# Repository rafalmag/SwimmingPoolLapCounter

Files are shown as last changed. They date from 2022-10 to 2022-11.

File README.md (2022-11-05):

# Swimming Pool Lap Counter

Swimming pool lap counter is a device for swimmers, so when practicing swimming in the pool they can easily count how many laps did they swim. 

The design requirements and solutions:
- battery powered  (powered by single cell 18650 powerbank)
- waterproof (fits into watertight food box)
- easy to trigger count increments (by capacitive touch sensing)
- lap count displayed and visible in bright sunlight (eInk display)
- lap increment trigger acknowledged (by buzzer and led)
- ability to reset counter without opening the box
- configuration should not interfere with main use case (lap count) and should not be triggered by mistake.

## Prototype

The ground wire should be grounded.
The blue wire should be connected to aluminum foil to sense touches.

## User interface

After starting the device the lap count resets to 0.
The capacitive sensor if "pressed" (senses touch) for a short time increments the lap count, emits sound and lights LED.
If "pressed" for a long time (>3 sec) it resets the counter.

Configuration options:
- beeper volume - by potentiometer (1k Ohm)
- LED brightness - by potentiometer (1k Ohm)
- touch sensing sensitivity threshold - by potentiometer (10k Ohm)
- (fixed) touch sensing resistor (20M Ohm) ~~- by potentiometer / dip switch~~ (idea abandoned - in practice dip switch and pot caused too much noise)
- increment counter by 2 mode - dip switch (by default increment by 1)
- 5s minimum lap increment interval - dip switch (by default - about 500ms)

## Hardware:
- Arduino Nano

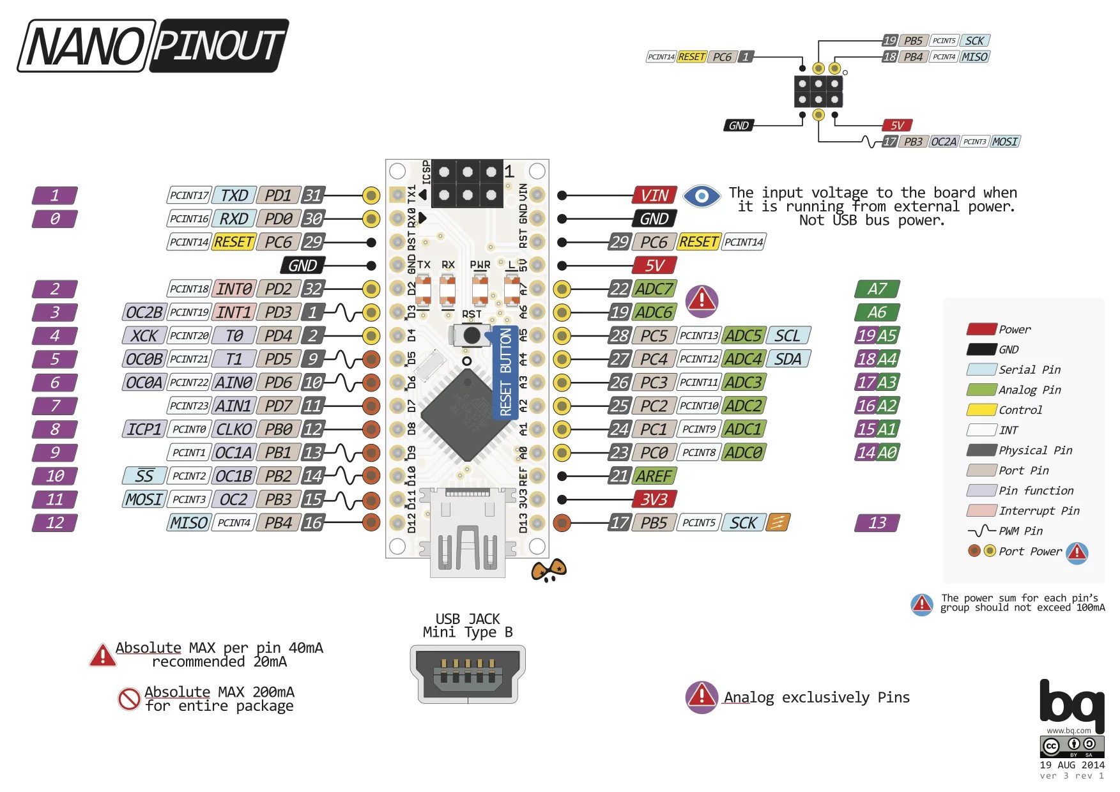
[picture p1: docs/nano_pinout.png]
nano pinout


- e-ink MH-ET LIVE - see https://github.com/MHEtLive/MH-ET-LIVE-E-Papers 
(my only works in 5V mode)

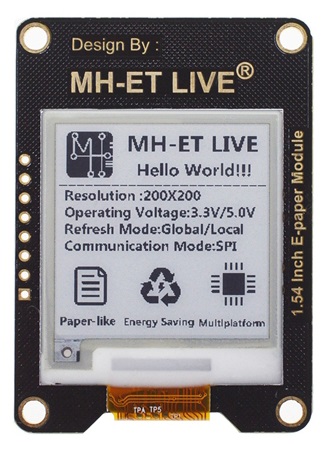
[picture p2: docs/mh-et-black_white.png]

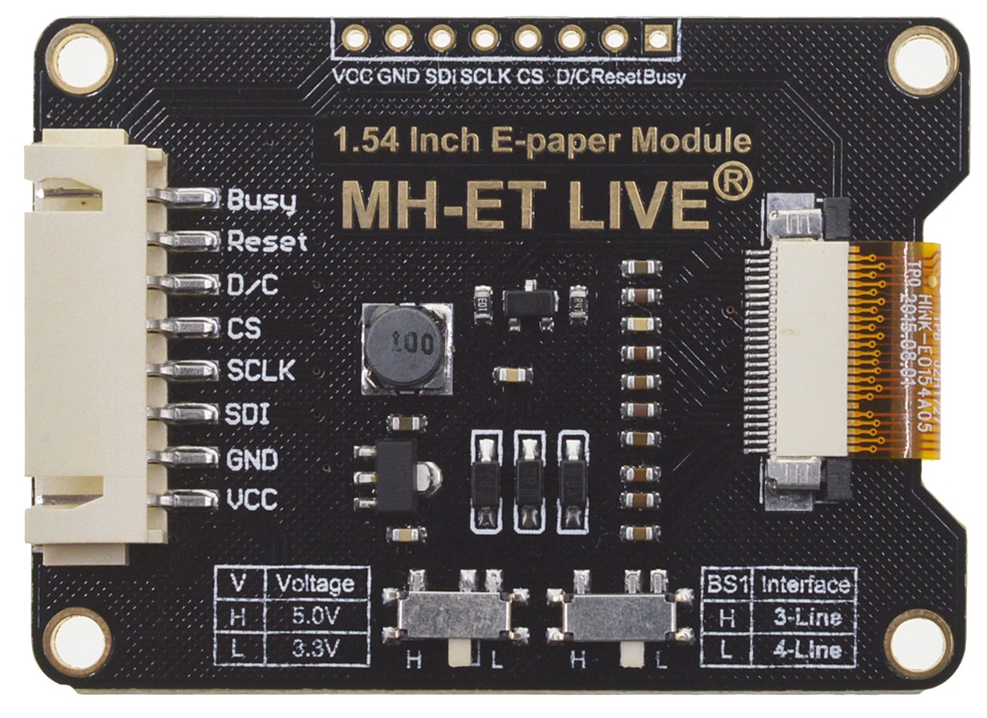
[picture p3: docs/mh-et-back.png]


- active buzzer (5V VCC (2mA when it beeps), GND)
 Consider: on/off toggle (hardware switch and maybe 1k-2kOhm variable resistor for VCC to adjust buzzer volume)
 IO pin connected via D4 .

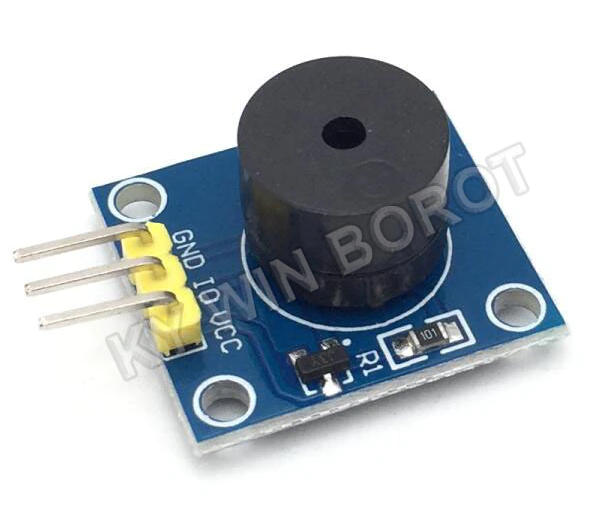
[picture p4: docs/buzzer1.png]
buzzer top

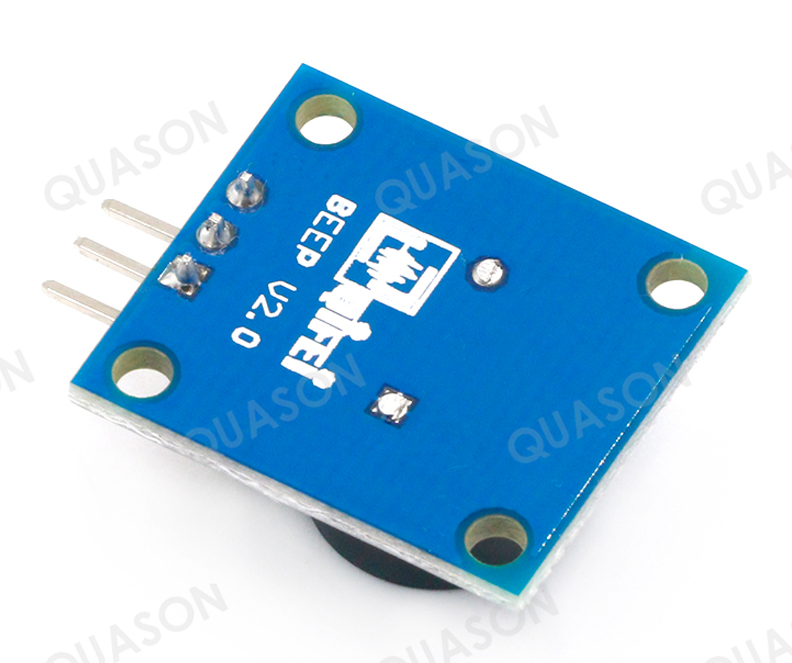
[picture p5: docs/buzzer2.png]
buzzer bottom


 - red 5mm led (2.2V, 10mA) (nano can output 40mA per IO pin, so it would be ok), connected via 330 Ohm resistor to D5

 - small powerbank (with 18650 battery, USB charging input and output - to power the nano and PCB)

## Wiring:

| e-ink / paper | Nano board |
|---|---|
| VCC | 5V |
| GND | GND |
| SDI (DIN) | D11(MOSI)  |
| CLK | D13(SCK) |
| CS | D10 |
| DC | D9 |
| RESET | D8 |
| BUSY | D7 |

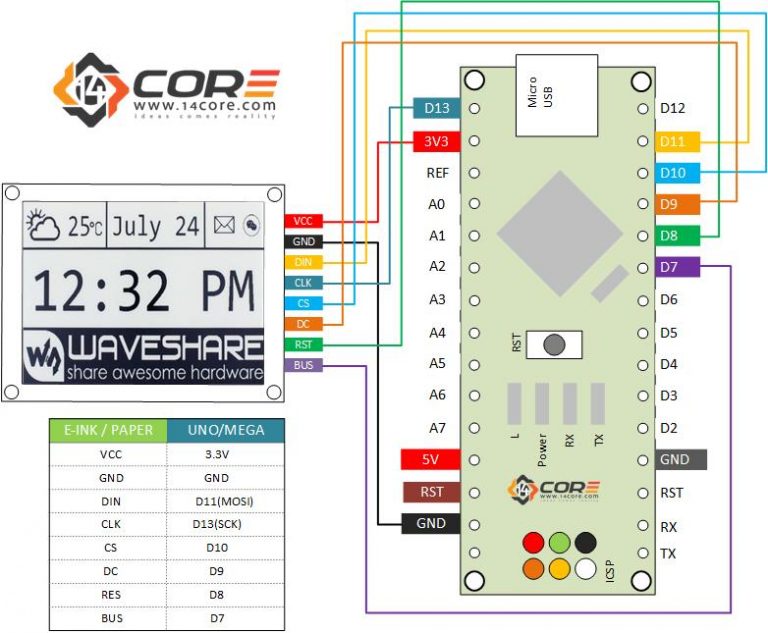
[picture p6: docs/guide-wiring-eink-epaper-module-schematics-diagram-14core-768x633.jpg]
wiring


## Schematic

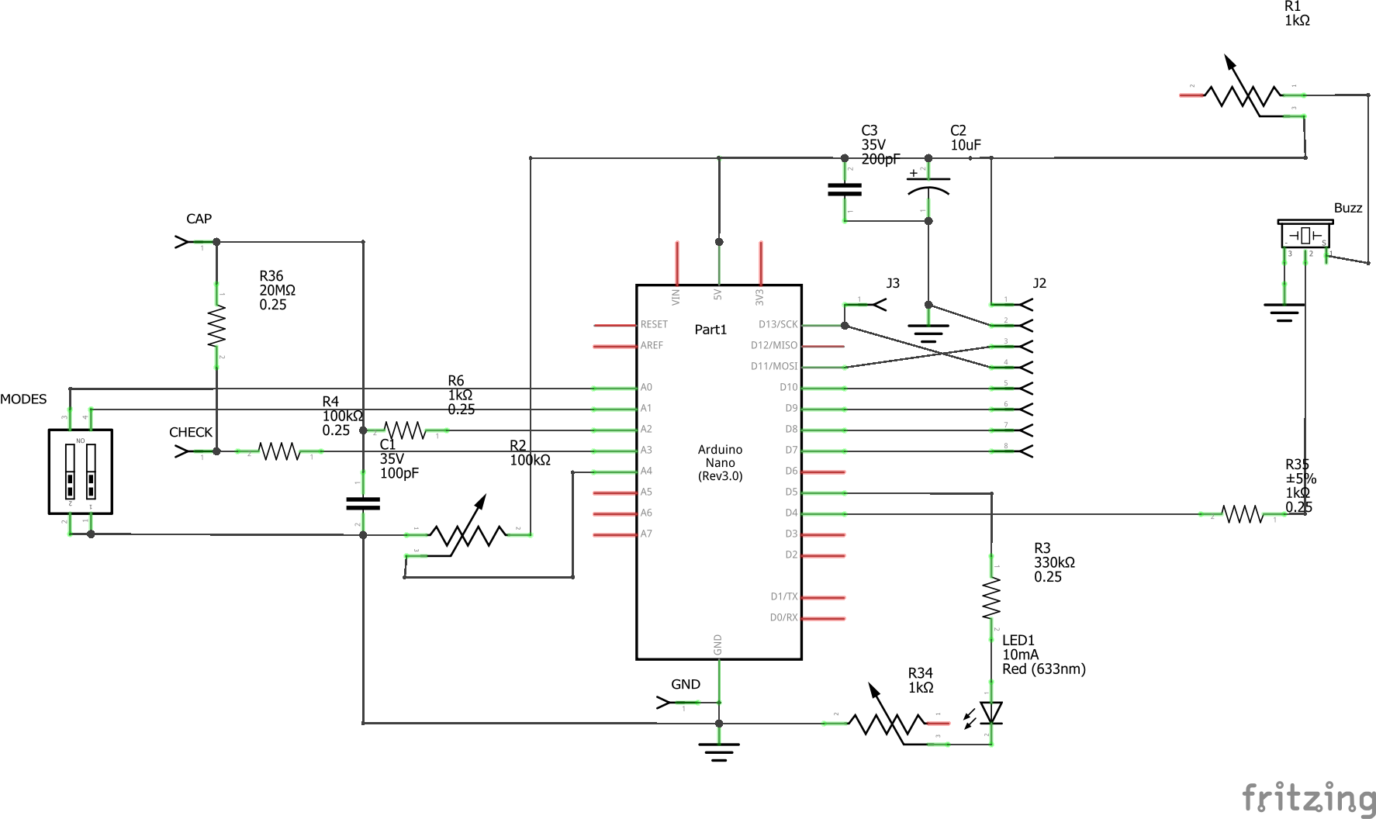
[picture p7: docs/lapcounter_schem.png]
schematic


## PCB design

PCB is based on prototype board 70 x 50mm with THT components soldered on top and SMD on bottom. 
The SMD resistor can be replaced with THT one in vertical mode.

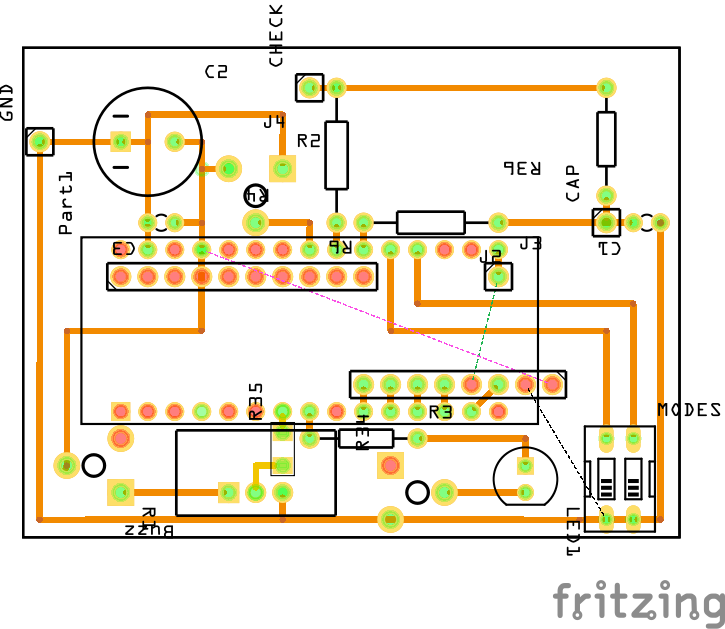
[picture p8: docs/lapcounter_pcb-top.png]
pcb


## Knows issues:
- the EPD library updates the screen in blocks that are multiplications of 8 pixels, but the RRE fonts lib is using blocks of different sizes. This causes minor glitches in the rendered fonts. Because of that issue I did not even tried to use antialiased fonts, but thanks to eInk high resolution the numbers are still readable

## TO DO ideas:
- deep sleep mode (think about user interface for waking up, putting to sleep)
- low battery warning (?)

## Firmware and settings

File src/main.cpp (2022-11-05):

#include <SPI.h>
#include <EPD1in54.h>
#include <EPDPaint.h>

#include "RREFont.h"
#include "rre_term_10x16.h"

#include <CapacitiveSensor.h>
#include <Button.h>
#include <ButtonEventCallback.h>
#include <CapacitiveButton.h>
#include "AnalogPin.h"

RREFont font;

#define COLORED 0
#define UNCOLORED 1

/**
 * Due to RAM not enough in Arduino UNO, a frame buffer is not allowed.
 * In this case, a smaller image buffer is allocated and you have to
 * update a partial display several times.
 * 1 byte = 8 pixels, therefore you have to set 8*N pixels at a time.
 */
unsigned char image[1024];
EPDPaint paint(image, 0, 0); // width should be the multiple of 8
EPD1in54 epd;                // default reset: 8, dc: 9, cs: 10, busy: 7

// D4 and D5
#define BUZZER_PIN PIN4
#define LED_PIN PIN5

#define THRESHOLD_PIN A4
AnalogPin thresholdPin(THRESHOLD_PIN);

#define TWO_LAP_MODE_PIN A0
#define MINIMUM_LAP_INCREMENT_INTERVAL_MODE_PIN A1

CapacitiveButton capacitiveButton = CapacitiveButton(A2, A3);

// screen size
#define SCR_WD 200
#define SCR_HT 200

int lapCount = 0;
#define MINIMUM_LAP_INCREMENT_INTERVAL_MS 5000L
unsigned long lastLapIncrement = millis() - MINIMUM_LAP_INCREMENT_INTERVAL_MS;
boolean canIncrement = false;

void customRect(int x, int y, int w, int h, int c)
{
  int extra_x = x % 8;
  int new_x = x - extra_x;

  paint.setWidth(w + extra_x);
  paint.setHeight(h);

  paint.clear(UNCOLORED);

  paint.drawFilledRectangle(0, 0, w - 1 + extra_x, h - 1, c);
  epd.setFrameMemory(paint.getImage(), new_x, y, paint.getWidth(), paint.getHeight());
  return;
}

void rmInit()
{
  // init-RM

  /**
   *  there are 2 memory areas embedded in the e-paper display
   *  and once the display is refreshed, the memory area will be auto-toggled,
   *  i.e. the next action of SetFrameMemory will set the other memory area
   *  therefore you have to clear the frame memory twice.
   */
  epd.clearFrameMemory(0xFF); // bit set = white, bit reset = black
  epd.displayFrame();
  epd.clearFrameMemory(0xFF); // bit set = white, bit reset = black
  epd.displayFrame();

  paint.setRotate(ROTATE_0);
  paint.setWidth(200);
  paint.setHeight(24);

  /* For simplicity, the arguments are explicit numerical coordinates */
  paint.clear(COLORED);
  paint.drawStringAt(30, 4, "SwimmingPoolLapCounter", &Font16, UNCOLORED);
  epd.setFrameMemory(paint.getImage(), 0, 10, paint.getWidth(), paint.getHeight());

  paint.clear(UNCOLORED);
  paint.drawStringAt(30, 4, "by Rafal Magda", &Font16, COLORED);
  epd.setFrameMemory(paint.getImage(), 0, 30, paint.getWidth(), paint.getHeight());

  epd.displayFrame();
  delay(2000);

  // init-RM end

  /**
   *  there are 2 memory areas embedded in the e-paper display
   *  and once the display is refreshed, the memory area will be auto-toggled,
   *  i.e. the next action of SetFrameMemory will set the other memory area
   *  therefore you have to clear the frame memory twice.
   */
  epd.clearFrameMemory(0xFF); // bit set = white, bit reset = black
  epd.displayFrame();
  epd.clearFrameMemory(0xFF); // bit set = white, bit reset = black
  epd.displayFrame();

  font.setScale(4);
  font.setSpacing(4);
  font.printStr(ALIGN_CENTER, 10, "1234");
  epd.displayFrame();
  font.printStr(ALIGN_CENTER, 50, "5678");
  epd.displayFrame();
}

void incrementLapCount()
{
  if (digitalRead(TWO_LAP_MODE_PIN) == LOW)
  {
    lapCount += 2;
  }
  else
  {
    lapCount++;
  }
  lastLapIncrement = millis();
}

// Use this function to configure the internal CapSense object to suit you. See the documentation at: http://playground.arduino.cc/Main/CapacitiveSensor
// This function can be left out if the defaults are acceptable - just don't call configureButton
void configureCapacitiveButton(CapacitiveSensor &capSense)
{
  // Set the capacitive sensor to timeout after 300ms
  capSense.set_CS_Timeout_Millis(300);
  // Set the capacitive sensor to auto-calibrate every 6secs
  capSense.set_CS_AutocaL_Millis(6000);
}
void dispNumber(int number);

// btn is a reference to the button that fired the event. That means you can use the same event handler for many buttons
void onButtonPressed(Button &btn)
{
  if (lastLapIncrement + MINIMUM_LAP_INCREMENT_INTERVAL_MS < millis() || digitalRead(MINIMUM_LAP_INCREMENT_INTERVAL_MODE_PIN) == HIGH)
  {
    digitalWrite(LED_PIN, HIGH);    // LED on
    digitalWrite(BUZZER_PIN, HIGH); // buzzer on
    canIncrement = true;
  }
}

void onReleaseCallbackFunction(Button &btn, uint_least16_t duration)
{
  if (canIncrement || digitalRead(MINIMUM_LAP_INCREMENT_INTERVAL_MODE_PIN) == HIGH)
  {
    incrementLapCount();
    Serial.print("button pressed ");
    Serial.println(lapCount);
    digitalWrite(BUZZER_PIN, LOW); // buzzer off
    dispNumber(lapCount);
    digitalWrite(LED_PIN, LOW); // LED off
    canIncrement = false;
    delay(250);
  }
  else
  {
    Serial.print("button pressed within MINIMUM_LAP_INCREMENT_INTERVAL_MS, lap count = ");
    Serial.println(lapCount);
    digitalWrite(BUZZER_PIN, LOW); // buzzer off
    digitalWrite(LED_PIN, LOW); // LED off
    //blink x2
    digitalWrite(LED_PIN, HIGH); // LED on
    delay(150);
    digitalWrite(LED_PIN, LOW); // LED off
    delay(150);
    digitalWrite(LED_PIN, HIGH); // LED on
    delay(150);
    digitalWrite(LED_PIN, LOW); // LED off
  }
}

// btn is a reference to the button that was held
// duration is how long the button was held for
void onHoldCallbackFunction(Button &btn, uint_least16_t duration)
{
  digitalWrite(BUZZER_PIN, LOW); // buzzer off
  if (canIncrement || digitalRead(MINIMUM_LAP_INCREMENT_INTERVAL_MODE_PIN) == HIGH){
    Serial.println("button LONG pressed ");
    lapCount = 0;
    dispNumber(lapCount);
    digitalWrite(LED_PIN, LOW); // LED off
    delay(250);
  } else {
    digitalWrite(LED_PIN, LOW); // LED off
    delay(100);
    //blink x2
    digitalWrite(LED_PIN, HIGH); // LED on
    delay(150);
    digitalWrite(LED_PIN, LOW); // LED off
    delay(150);
    digitalWrite(LED_PIN, HIGH); // LED on
    delay(150);
    digitalWrite(LED_PIN, LOW); // LED off
  }
}

long threshold;
void setButtonThreshold()
{
  threshold = map(thresholdPin.readSmoothed(), 0, 1023, 1, 10000L);
  // Serial.print("threshold ");
  // Serial.println(threshold);
  capacitiveButton.setThreshold(threshold);
}

void setup()
{
  pinMode(THRESHOLD_PIN, INPUT);
  pinMode(MINIMUM_LAP_INCREMENT_INTERVAL_MODE_PIN, INPUT_PULLUP);
  pinMode(TWO_LAP_MODE_PIN, INPUT_PULLUP);
  pinMode(LED_PIN, OUTPUT);
  pinMode(BUZZER_PIN, OUTPUT);
  // put your setup code here, to run once:
  Serial.begin(9600);
  capacitiveButton.configureButton(configureCapacitiveButton);

  thresholdPin.setSmoothWeight(8);
  setButtonThreshold();

  capacitiveButton.setNumberOfSamples(25);
  capacitiveButton.onPress(onButtonPressed);
  if (capacitiveButton.onRelease(10, 3000 - 100, onReleaseCallbackFunction) != attSuccessful)
  {
    Serial.print("Button attach onRelease callback failed");
    return;
  }
  if (capacitiveButton.onHold(3000, onHoldCallbackFunction) != attSuccessful)
  {
    Serial.print("Button attach onHold callback failed");
    return;
  }

  if (epd.init(lutFullUpdate) != 0)
  {
    Serial.print("e-Paper init failed");
    return;
  }

  font.init(customRect, SCR_WD, SCR_HT); // custom fillRect function and screen width and height values
  // font.setColor(COLORED, UNCOLORED); //this clears the background, but is 2x slower
  font.setColor(COLORED); // this requires explicit cleanup
  font.setFont(&rre_term_10x16);

  // rmInit();

  dispNumber(0);
}

char buf[10];
void dispNumber(int number)
{
  // Serial.print("Disp number ");
  // Serial.print(number);
  // consider use of this every %10 laps, but then consider font.setColor(COLORED, UNCOLORED) near line 106
  epd.clearFrameMemory(0xFF); // bit set = white, bit reset = black

  itoa(number, buf, 10);

  if (0 <= number && number <= 9)
  {
    font.setFont(&rre_term_10x16); // set font resets spacing
    font.setScale(10, 10);
    font.printStr(ALIGN_CENTER, 20, buf);
  }
  else if (10 <= number && number <= 99)
  {
    font.setFont(&rre_term_10x16);
    font.setScale(8);
    font.setSpacing(4);
    font.printStr(ALIGN_CENTER, 40, buf);
  }
  else if (100 <= number && number <= 999)
  {
    font.setFont(&rre_term_10x16);
    font.setScale(5, 7);
    font.setSpacing(4);
    font.printStr(ALIGN_CENTER, 52, buf);
  }
  else if (1000 <= number && number <= 9999)
  {
    font.setFont(&rre_term_10x16);
    font.setScale(4, 6);
    font.setSpacing(4);
    font.printStr(ALIGN_CENTER, 48, buf);
  }
  else
  {
    font.setFont(&rre_term_10x16); // set font resets spacing
    font.setScale(2, 2);
    font.printStr(ALIGN_CENTER, 20, "out of range");
  }
  // Serial.println(" OK");
  epd.displayFrame();
}

void loop()
{
  setButtonThreshold();
  capacitiveButton.update();
}

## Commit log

2022-10-09 led and buzzer
    [pot.fzz]
2022-10-09 cap sensor
2022-10-09 threshold pin
2022-10-11 before assembly
    [lapcounter.fzz, pot.fzz]
